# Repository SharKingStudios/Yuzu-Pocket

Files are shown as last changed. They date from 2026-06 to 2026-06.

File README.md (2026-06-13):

# Yuzu Pocket - A PCB Business card that runs Linux!

### compact and delightfully unnecessary.

---

## Renders
*Visuals because everyone loves eye candy.*

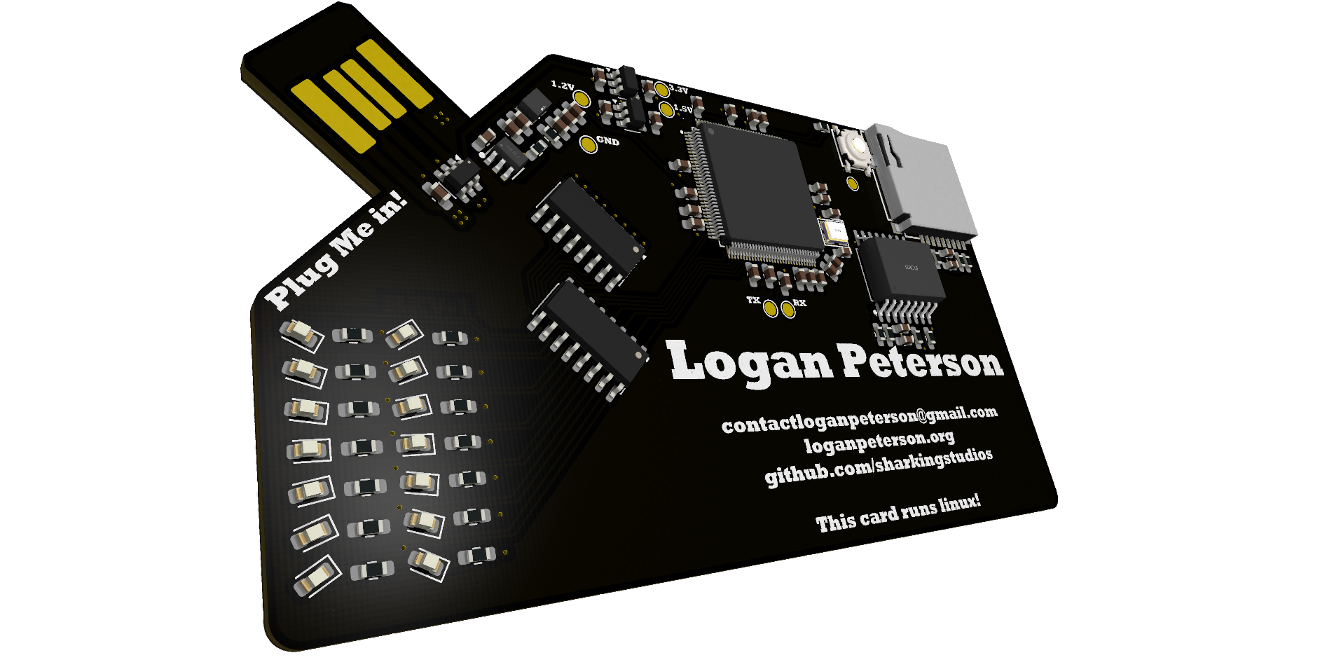
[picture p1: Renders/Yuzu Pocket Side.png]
Side PCB Render

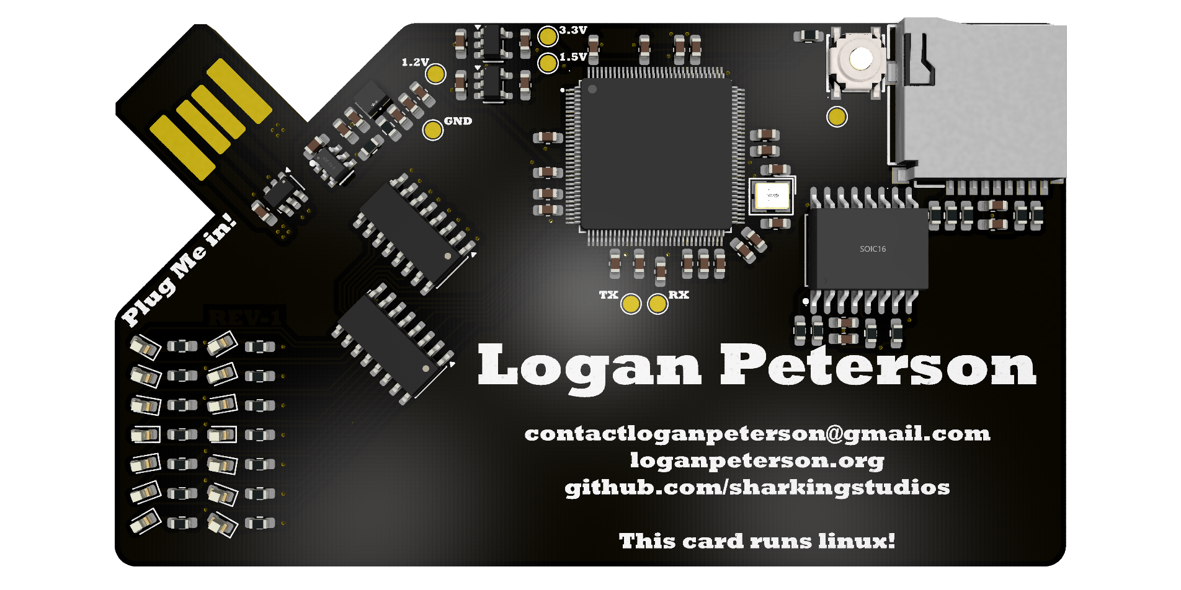
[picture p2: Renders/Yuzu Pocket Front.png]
Top PCB Render

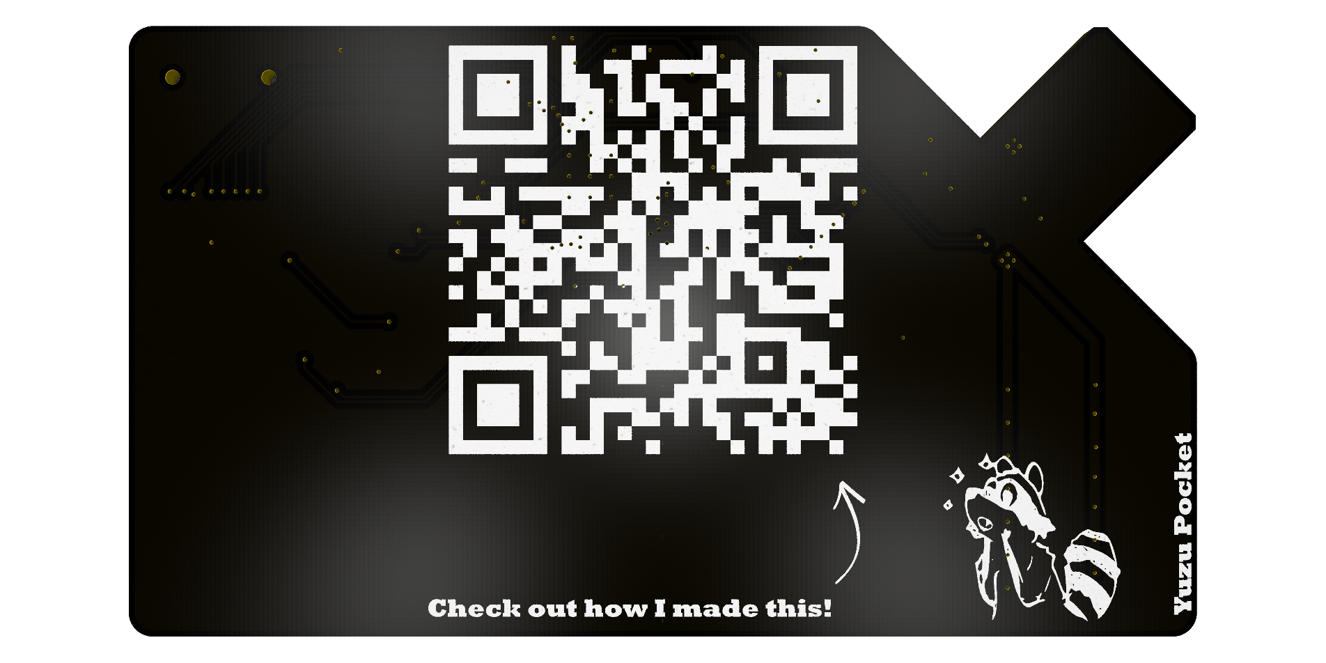
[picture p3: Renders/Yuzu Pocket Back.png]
Back PCB Render

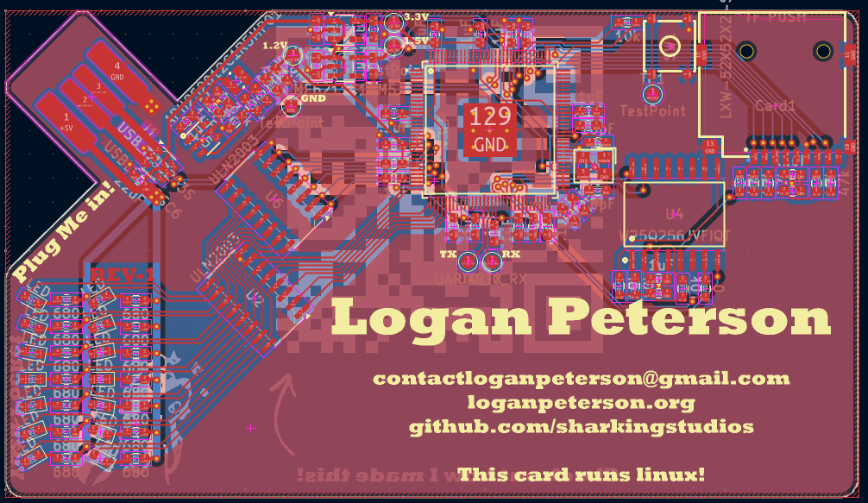
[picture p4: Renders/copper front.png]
Routing Glamour Shot

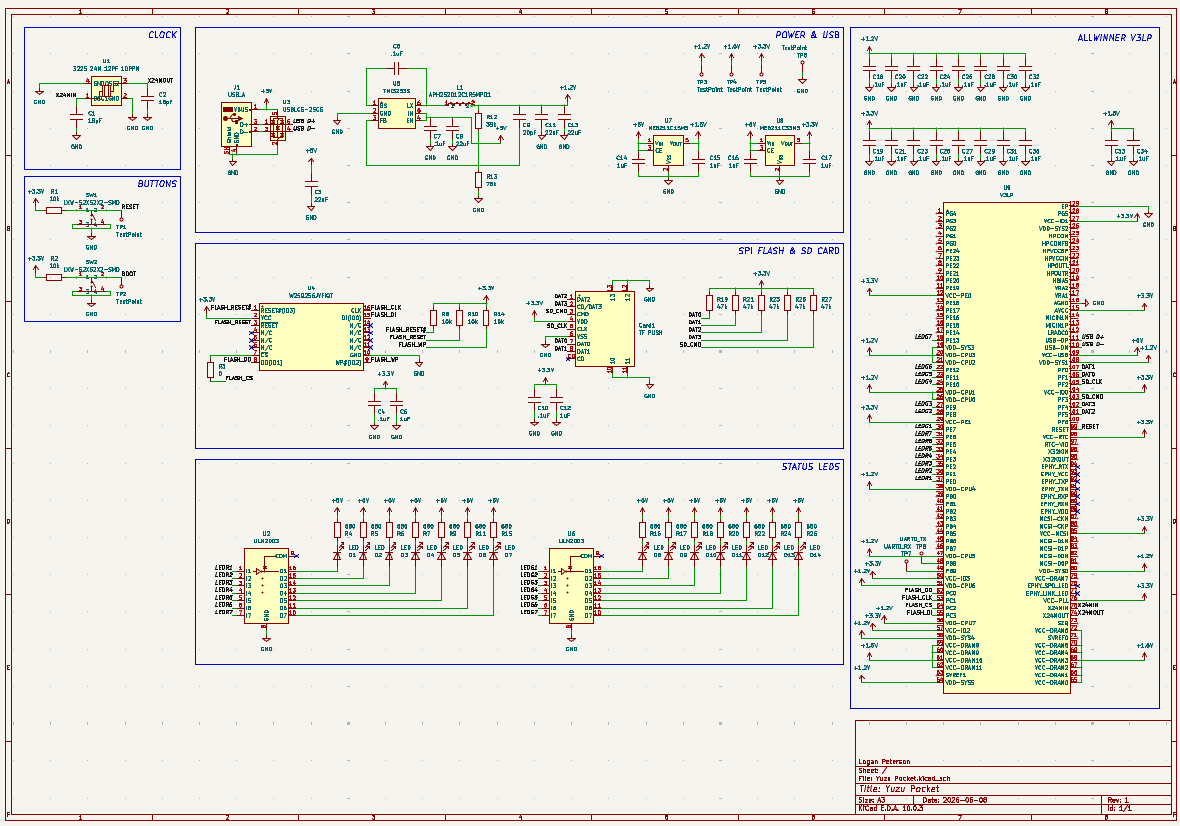
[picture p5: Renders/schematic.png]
Schematic Picture


---

## BOM
All the processors and storage sit **[here](/BOM.csv)**.

**Main characters:**
 - **Processor:** Allwinner V3LP
 - **Onboard Storage:** Winbond W25Q256JVFIQT 256Mbit SPI flash
 - **More Storage:** Micro SD Card Slot
 - **Blinken Lights:** Red and Green
- **Misc:** Boot circuitry, reset logic, pull-ups, decoupling, and other necessary magic

(See `BOM.md` for full part values, footprints, and sourcing.)

---

## What is this?

The **Yuzu Pocket** is a **Business Card that runs Linux** built around an Allwinner V3LP processor, designed to give important individuals my portfolio with some pizzazz!

It does this using its onboard USB port, integrated right into the PCB copper, to talk to the host computer. To keep things interesting, the board exposes itself as a USB gadget, giving the host multiple points of access into the board. 

## How It Works

On startup, the board will connect to the host computer and expose itself as a network device, as well as a mass storage device.

The mass storage that opens acts as the quick menu, and links the user to the more interesting parts of the project, including the hosted webpage at loganpeterson.local that exposes a shell, giving the user direct access into the device (where they can play the integrated terminal games / demos)

At a high level:

1. **The card is plugged into a USB port**
3. The V3LP boots **U-Boot and Linux**
4. Linux creates a composite USB gadget containing:
   - A small read-only help drive
   - A USB network interface
   - A serial interface
5. The host receives an address on the private USB network
6. The card advertises itself as **`loganpeterson.local`**
7. Opening the included shortcut launches a browser-based terminal
8. The visitor is now using a Linux computer thats the size of a business card

No extra special applications are required other than just having a host computer.

---

## Features

### A Real Linux Computer

Yuzu Pocket is not a microcontroller pretending to be a computer. The Allwinner V3LP contains a **32-bit ARM Cortex-A7 processor** and **64 MB of integrated DDR2 RAM**, giving the board enough room for:

- U-Boot
- A Linux kernel
- BusyBox userspace
- USB gadget services
- A web terminal
- Small native programs, games, and network demos

The firmware is intentionally based on **Buildroot** rather than a full desktop distribution.

---

### Plug-In USB Experience

The copper fingers on the edge of the PCB form a USB-A connector. Plugging the card into a computer is intended to provide both power and communication.

The Linux USB gadget configuration can expose several functions over that single connection:

- **Mass storage**
  - Shows `HOW_TO_USE.txt`
  - Includes browser shortcut files
  - Acts as the card's quick-start menu
- **USB Ethernet**
  - Creates a private network between the host and Yuzu Pocket
  - Uses `10.0.0.1` as a fallback address
- **USB serial**
  - Provides another route into the Linux console
- **Web terminal**
  - Served by [`ttyd`](https://github.com/tsl0922/ttyd)
  - Intended URL: **`http://loganpeterson.local:7681/`**

---

### Onboard Storage

Yuzu Pocket has two storage paths:

| Storage | Capacity | Purpose |
|---|---:|---|
| Winbond W25Q256 SPI NOR | 256 Mbit / 32 MB | Compact onboard firmware and persistent assets |
| microSD | Card dependent | Development, recovery, larger Linux images, and *experiments* |

The initial development image targets microSD because it is easier to rebuild and recover. The final compact image is intended to fit within the **32 MB onboard SPI NOR**, using a small kernel and compressed root filesystem.

That storage budget is tight enough to be interesting, but large enough for a fun Linux userspace.

---

### Fourteen Blinken Lights

The card includes:

- **7 red LEDs**
- **7 green LEDs**
- **14 total individually controlled channels**

The LEDs are driven through two ULN2003 Darlington transistor arrays. Linux sees them as GPIO-controlled indicators, allowing them to be used for:

- Boot progress
- Storage activity
- USB connection status
- Network activity
- Error codes
- Loading animations
- *Gratuitous blinking*

Because silent business cards are suspicious.

---

## Firmware

Firmware lives in **[`Firmware/`](/Firmware/)** and is organized as a Buildroot external tree.

The closest upstream starting point is the **Allwinner V3s / Lichee Pi Zero** support found in U-Boot and Linux. V3LP is treated as V3s-like for the initial port, with DRAM initialization being the part most likely to require V3LP-specific work.

See the **[firmware README](/Firmware/README.md)** for build commands, image layout, and current implementation details.

## What Can It Run?

The target is small native Linux software.

This includes:

- Terminal games
- LED animations
- Tiny HTTP services
- Network experiments
- My Portfolio
- A minimal Minecraft-protocol-compatible server
- Whatever fits inside the remaining storage budget

> There is an integration point reserved for [`p2r3/bareiron`](https://github.com/p2r3/bareiron), a compact C Minecraft server experiment. It is not enabled by default yet because upstream requires generated Minecraft registry data before compilation (and I havent gotten to that).

---

## Why?

The **Yuzu Pocket** exists because I wanted a portfolio piece that people would actually remember, rather than another ordinary business card or QR code printed on cardstock (though it has one too!).

It combines my interest in PCB design, embedded systems, and questionable software experiments into something small enough to carry everywhere and hand out to people.

---

## Contributing

Ideas, fixes, experiments, and constructive criticism are welcome.

- Open an issue
- Submit a pull request
- Suggest a tiny program that belongs on the card
- Improve the V3LP boot support
- Help reduce the image size
- Find a fun use for fourteen LEDs
- Make the DOOM situation worse

Please keep PCB and firmware changes clearly separated. Hardware files live in `PCB/`; firmware and build integration belong in `Firmware/`.

---

## Disclaimer

This is an open hardware and firmware project under active development.

It includes:

- Custom power regulation
- Fine-pitch PCB assembly
- USB hardware
- Boot firmware
- Flashing tools capable of overwriting storage
- Enough exposed engineering decisions to create exciting new failure modes

If you overwrite the wrong drive, short a power rail, install a component backward, or release the magic smoke, the business card will be significantly less useful at networking events.

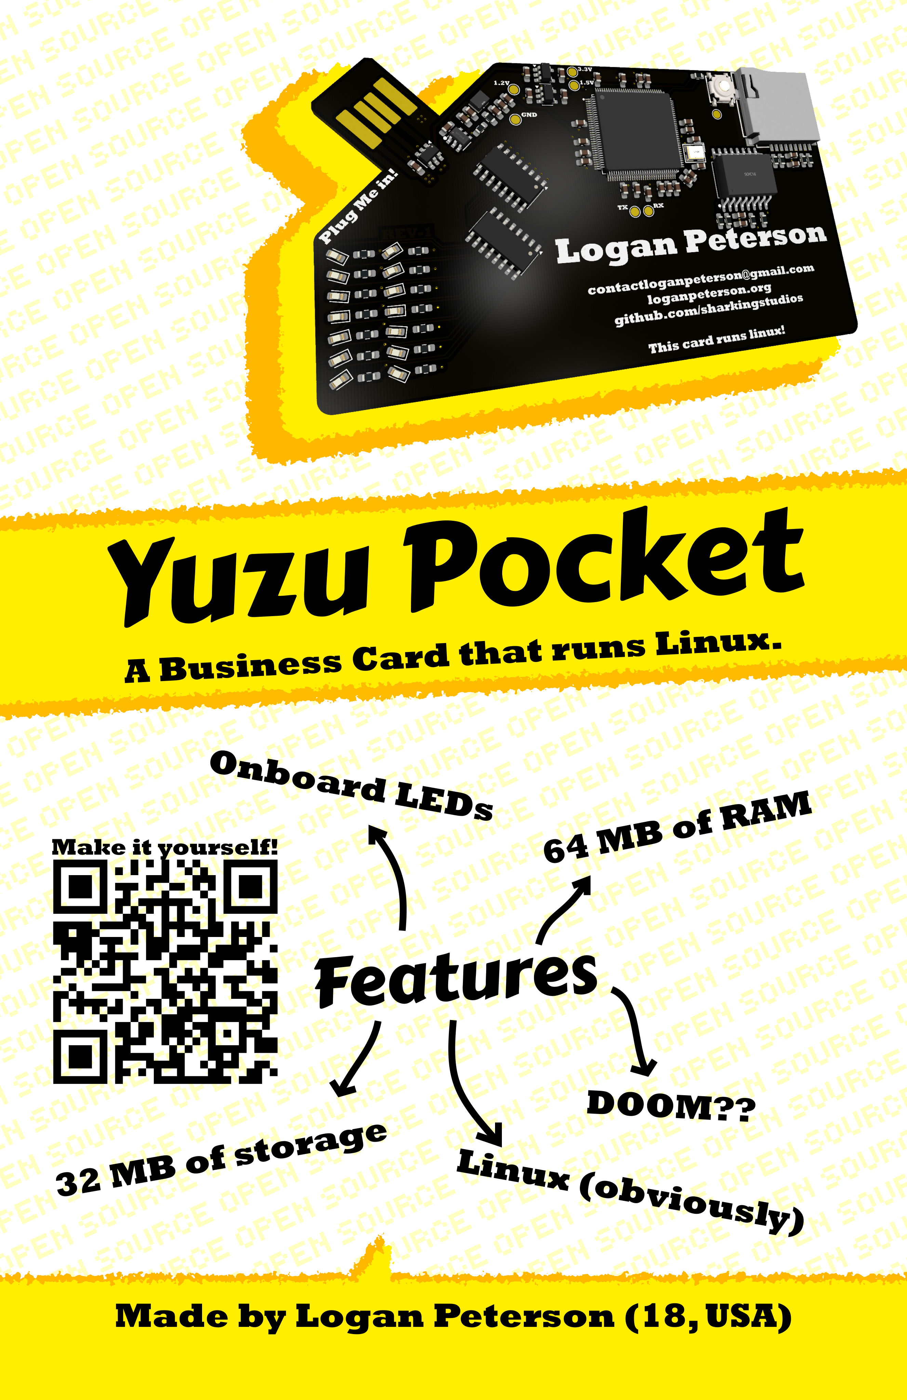
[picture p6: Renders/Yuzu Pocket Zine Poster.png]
Zine Page!


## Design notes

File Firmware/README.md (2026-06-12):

# Yuzu Pocket Firmware

Minimal Linux firmware for the Yuzu Pocket Allwinner V3LP board.

This directory is a Buildroot br2-external tree. It keeps Yuzu Pocket board support in this repo while using a clean upstream Buildroot checkout in `Firmware/buildroot/`.

## Target Image

- U-Boot SPL + U-Boot for the V3s-like sunxi boot path.
- UART0 console on PB8/PB9 at 115200 8N1.
- microSD boot on SDC0/PF0-PF5.
- 64 MB RAM.
- BusyBox rootfs.
- SPI NOR support for W25Q256 JEDEC/MTD detection.
- 14 GPIO LEDs, PE0-PE13, active high through ULN2003 inputs.
- USB gadget setup for ACM serial, ECM network, and a read-only help volume.
- Browser terminal through ttyd at `http://loganpeterson.local:7681/`.
- DHCP/DNS fallback at `http://10.0.0.1:7681/`.

## Quick Start

Run from a Linux or WSL shell with normal Buildroot dependencies installed:

```sh
cd Firmware
sh scripts/fetch-buildroot.sh
sh scripts/build.sh
```

The expected final image is:

```text
Firmware/output/yuzu_pocket/images/sdcard.img
```

## User-Facing Plug-In Flow

When the board boots over USB, it should expose:

- a small read-only help drive with `HOW_TO_USE.txt` and terminal shortcut files,
- a USB network at `10.0.0.1`,
- mDNS name `loganpeterson.local`,
- a ttyd web shell on port `7681`.

The files shown to a user are kept in:

```text
board/yuzu-pocket/rootfs_overlay/opt/yuzu-pocket/help/
```

## Source Baseline

- Buildroot: `2026.05`
- Linux: `6.12.93` longterm
- U-Boot: Buildroot-managed custom version `2026.04`
- Closest upstream board model: Allwinner V3s / Lichee Pi Zero

The V3LP-specific assumption is concentrated in the board DTS and U-Boot config fragment. If SPL DRAM init needs vendor V3LP parameters, those belong in `board/yuzu-pocket/uboot/`.

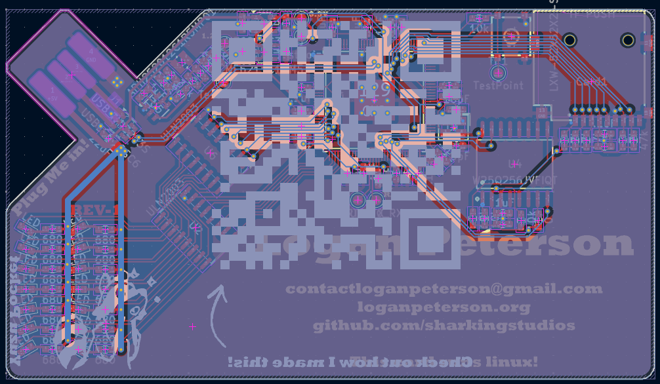
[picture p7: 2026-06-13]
Renders/copper back.png

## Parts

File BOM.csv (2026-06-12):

Value | Qty | Price Ea. | Price total (MOQ) | LCSC link
18pF capacitor 0603 | 2 | 0.0047 | 0.47 | https://www.lcsc.com/product-detail/C107040.html
22uF capacitor 0603 | 4 | 0.23 | 0.45 | https://www.lcsc.com/product-detail/C59461.html
0.1uF capacitor 0603 | 22 | 0.0101 | 1.01 | https://www.lcsc.com/product-detail/C15725.html
1uF capacitor 0603 | 6 | 0.0089 | 0.45 | https://www.lcsc.com/product-detail/C95843.html
20pF capacitor 0603 | 1 | 0.0047 | 0.047 | https://www.lcsc.com/product-detail/C105621.html
SHOU HAN TF PUSH microSD card socket | 1 | 0.063 | 0.63 | https://www.lcsc.com/product-detail/C393941.html
LED 0603 RED | 7 | 0.0035 | 0.35 | https://www.lcsc.com/product-detail/C965799.html
LED 0603 GREEN | 7 | 0.0050 | 0.5 | https://www.lcsc.com/product-detail/C965804.html
APH252012C1R5MP01 (1.5uH SMD inductor) | 1 | 0.034 | 0.68 | https://www.lcsc.com/product-detail/C42455360.html
10k ohm resistor 0603 | 5 | 0.0011 | 0.11 | https://www.lcsc.com/product-detail/C50397040.html
680 ohm resistor 0603 | 14 | 0.001 | 0.10 | https://www.lcsc.com/product-detail/C54921071.html
39k ohm resistor 0603 | 1 | 0.001 | 0.10 | https://www.lcsc.com/product-detail/C54921034.html
78k ohm resistor 0603 | 1 | 0.001 | 0.10 | https://www.lcsc.com/product-detail/C3016126.html
47k ohm resistor 0603 | 5 | 0.0014 | 0.14 | https://www.lcsc.com/product-detail/C2907173.html
LXW-52X52X2-SMD tactile switch | 2 | 0.023 | 0.45 | https://www.lcsc.com/product-detail/C53447014.html
SOSET 3225 24MHz 12pF 10ppm crystal | 1 | 0.069 | 0.69 | https://www.lcsc.com/product-detail/C5181479.html
ULN2003A Darlington transistor array SOIC-16 | 2 | 0.141 | 0.70 | https://www.lcsc.com/product-detail/C7512.html
USBLC6-2SC6 USB ESD protection SOT-23-6 | 1 |  |  | https://www.lcsc.com/product-detail/C7519.html
TMI TMI3253S DC-DC converter SOT-23-6 | 1 | 0.092 | 0.27 | https://www.lcsc.com/product-detail/C478943.html
ME6211C15M5 1.5V LDO regulator SOT-23-5 | 1 | 0.15 | 0.77 | https://www.lcsc.com/product-detail/C53100.html
ME6211C33M5 3.3V LDO regulator SOT-23-5 | 1 | 0.051 | 0.51 | https://www.lcsc.com/product-detail/C82942.html
(For adacent project) OPSCO Optoelectronics SK6812MINI-E | 70 | 0.07 | 4.87 | https://www.lcsc.com/product-detail/C5149201.html
(For adjacent project) ST(Semtech) 1N4148W | 70 | 0.0113 | 2.26 | https://www.lcsc.com/product-detail/C81598.html
Allwinner V3LP processor LQFP-128 | 1 | 2.33 | 4.66 | https://www.superbuy.com/en/page/buy/?url=https%3A%2F%2Fdetail.1688.com%2Foffer%2F1050707306347.html
Winbond W25Q256JVFIQT 256Mbit SPI flash | 1 | 0.4 | 4.00 | https://www.superbuy.com/en/page/buy/?url=https%3A%2F%2Fdetail.1688.com%2Foffer%2F684579822646.html
Estimated Factory Shipping |  |  | 15.00
LCSC Merchandise Subtotal |  |  |  | 17.38
LCSC Shipping Estimate |  |  |  | 12.84
LCSC Taxes Buffer |  |  |  | 3.00
LCSC Total |  |  |  | 33.22
JLCPCB Fabrication | 5 |  |  | 3.30
JLCPCB Stencil | 1 |  |  | 4.00
JLCPCB Shipping Estimate |  |  |  | 13.55
JLCPCB Taxes Buffer |  |  |  | 3.00
JLCPCB Total |  |  |  | 20.55
Grand Total |  |  |  | 53.77

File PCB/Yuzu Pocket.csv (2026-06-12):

Reference | Qty | Value | DNP | Exclude from BOM | Exclude from Board | Footprint | Datasheet
C1,C2 | 2 | 18pF |  |  |  | Capacitor_SMD:C_0603_1608Metric_Pad1.08x0.95mm_HandSolder
C3,C8,C11,C13 | 4 | 22uF |  |  |  | Capacitor_SMD:C_0603_1608Metric_Pad1.08x0.95mm_HandSolder
C4,C5,C7,C10,C18,C19,C20,C21,C22,C23,C24,C25,C26,C27,C28,C29,C30,C31,C32,C33,C34,C35 | 22 | .1uF |  |  |  | Capacitor_SMD:C_0603_1608Metric_Pad1.08x0.95mm_HandSolder
C6,C12,C14,C15,C16,C17 | 6 | 1uF |  |  |  | Capacitor_SMD:C_0603_1608Metric_Pad1.08x0.95mm_HandSolder
C9 | 1 | 20pF |  |  |  | Capacitor_SMD:C_0603_1608Metric_Pad1.08x0.95mm_HandSolder
Card1 | 1 | TF PUSH |  |  |  | easyeda2kicad:TF-SMD_TF-PUSH | https://lcsc.com/product-detail/Connector-Card-Sockets_SHOU-HAN-SHOU-HAN-TFDeck-TF-Deck_C393941.html
D1,D2,D3,D4,D5,D6,D7,D8,D9,D10,D11,D12,D13,D14 | 14 | LED |  |  |  | LED_SMD:LED_0603_1608Metric
L1 | 1 | APH252012C1R5MP01 |  |  |  | easyeda2kicad:IND-SMD_APH252012C3R3MP01 | https://www.lcsc.com/datasheet/C42455360.pdf
R1,R2,R8,R10,R14 | 5 | 10k |  |  |  | Resistor_SMD:R_0603_1608Metric_Pad0.98x0.95mm_HandSolder
R3 | 1 | 0 |  |  |  | Resistor_SMD:R_0603_1608Metric_Pad0.98x0.95mm_HandSolder
R4,R5,R6,R7,R9,R11,R15,R16,R17,R18,R20,R22,R24,R26 | 14 | 680 |  |  |  | Resistor_SMD:R_0603_1608Metric_Pad0.98x0.95mm_HandSolder
R12 | 1 | 39k |  |  |  | Resistor_SMD:R_0603_1608Metric_Pad0.98x0.95mm_HandSolder
R13 | 1 | 78k |  |  |  | Resistor_SMD:R_0603_1608Metric_Pad0.98x0.95mm_HandSolder
R19,R21,R23,R25,R27 | 5 | 47k |  |  |  | Resistor_SMD:R_0603_1608Metric_Pad0.98x0.95mm_HandSolder
SW1,SW2 | 2 | LXW-52X52X2-SMD |  |  |  | easyeda2kicad:SW-SMD_4P-L5.2-W5.2-P5.80-LS6.4 | https://www.lcsc.com/datasheet/C53447014.pdf
TP1,TP2,TP3,TP4,TP5,TP6 | 6 | TestPoint |  |  |  | TestPoint:TestPoint_Pad_D1.5mm
TP7 | 1 | UART0_RX |  |  |  | TestPoint:TestPoint_Pad_D1.5mm
TP8 | 1 | UART0_TX |  |  |  | TestPoint:TestPoint_Pad_D1.5mm
U1 | 1 | 3225 24M 12PF 10PPM |  |  |  | easyeda2kicad:CRYSTAL-SMD_4P-L3.2-W2.5-BL | https://www.lcsc.com/datasheet/C5181479.pdf
U2,U6 | 2 | ULN2003 |  |  |  | Package_SO:SOIC-16_3.9x9.9mm_P1.27mm | http://www.ti.com/lit/ds/symlink/uln2003a.pdf
U3 | 1 | USBLC6-2SC6 |  |  |  | Package_TO_SOT_SMD:SOT-23-6 | https://www.st.com/resource/en/datasheet/usblc6-2.pdf
U4 | 1 | W25Q256JVFIQT |  |  |  | easyeda2kicad:SOIC-16_L10.3-W7.5-P1.27-LS10.3-BL | https://lcsc.com/product-detail/FLASH_Winbond-Elec-W25Q256JVFIQT_C779876.html
U5 | 1 | TMI3253S |  |  |  | easyeda2kicad:SOT-23-6_L2.9-W1.6-P0.95-LS2.8-BL | https://lcsc.com/product-detail/DC-DC-Converters_TMI-TMI3253S_C478943.html
U7 | 1 | ME6211C15M5 |  |  |  | Package_TO_SOT_SMD:SOT-23-5 | https://www.lcsc.com/datasheet/lcsc_datasheet_2304140030_MICRONE-Nanjing-Micro-One-Elec-ME6211C33R5G_C235316.pdf
U8 | 1 | ME6211C33M5 |  |  |  | Package_TO_SOT_SMD:SOT-23-5 | https://www.lcsc.com/datasheet/lcsc_datasheet_2304140030_MICRONE-Nanjing-Micro-One-Elec-ME6211C33R5G_C235316.pdf
U9 | 1 | V3LP |  |  |  | easyeda2kicad:LQFP-128_L14.0-W14.0-P0.40-LS16.0-BL-EP5.6 | https://www.lcsc.com/datasheet/C5350798.pdf

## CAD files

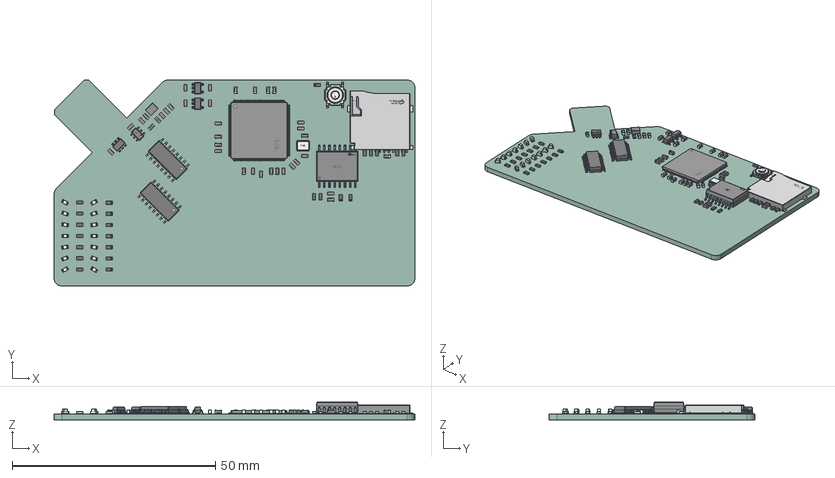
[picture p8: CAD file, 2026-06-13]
PCB/.step
88.9 x 50.8 x 4.40 mm
R_0603_1608Metric x 26
OSC-SMD_L3.2-W1.5-H0.8
SOIC-16_L10.3-W7.5-H2.7-LS10.3-P1.27
C_0603_1608Metric x 35
LED_0603_1608Metric x 14
SOT-23-6
TF-SMD_TF-PUSH
IND-SMD_APH252012C3R3MP01
SOIC-16_3.9x9.9mm_P1.27mm x 2
SOT-23-5 x 2
LQFP-128_L14.0-W14.0-P0.40-LS16.0-BL-EP5.6
SW-SMD_4P-L5.2-W5.2-P5.80-LS6.4
SOT-23-6_L2.9-W1.6-H1.5-LS2.8-P0.95
Yuzu Pocket_PCB

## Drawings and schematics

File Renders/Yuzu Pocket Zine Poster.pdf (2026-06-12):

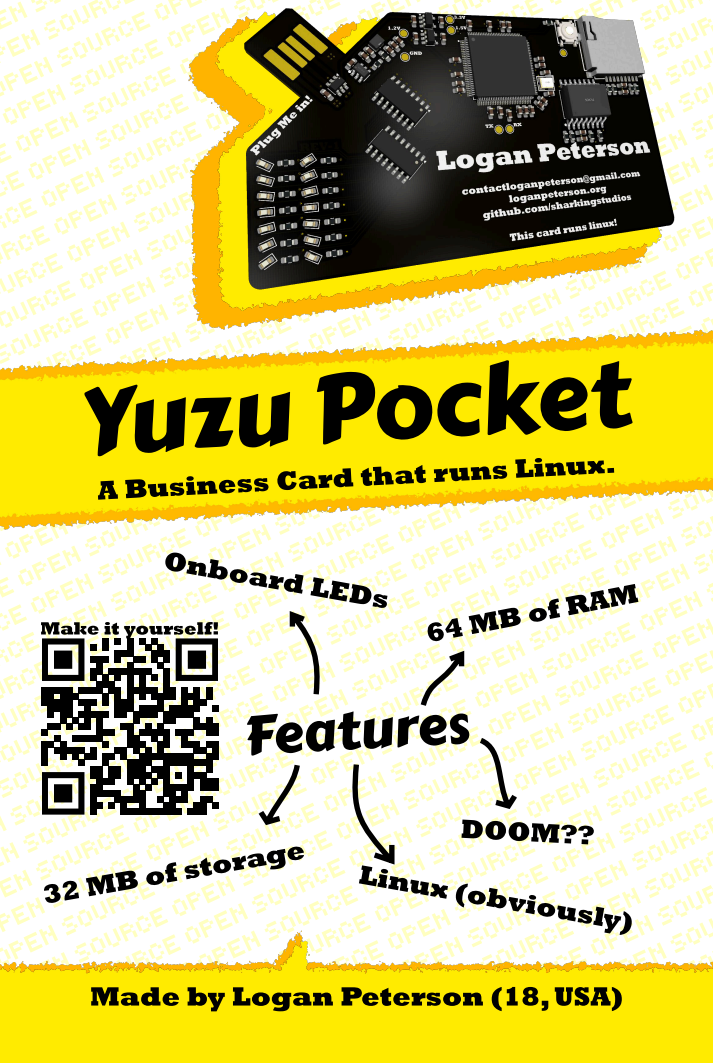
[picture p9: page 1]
Yuzu Pocket; Onboard LEDs; Features; Linux (obviously); DOOM??

OPEN SOURCE OPEN SOURCE OPEN SOURCE OPEN SOURCE OPEN SOURCE OPEN SOURCE OPEN SOURCE

A Business Card that runs Linux.

64 MB of RAM

Make it yourself!

32 MB of storage

Made by Logan Peterson (18, USA)

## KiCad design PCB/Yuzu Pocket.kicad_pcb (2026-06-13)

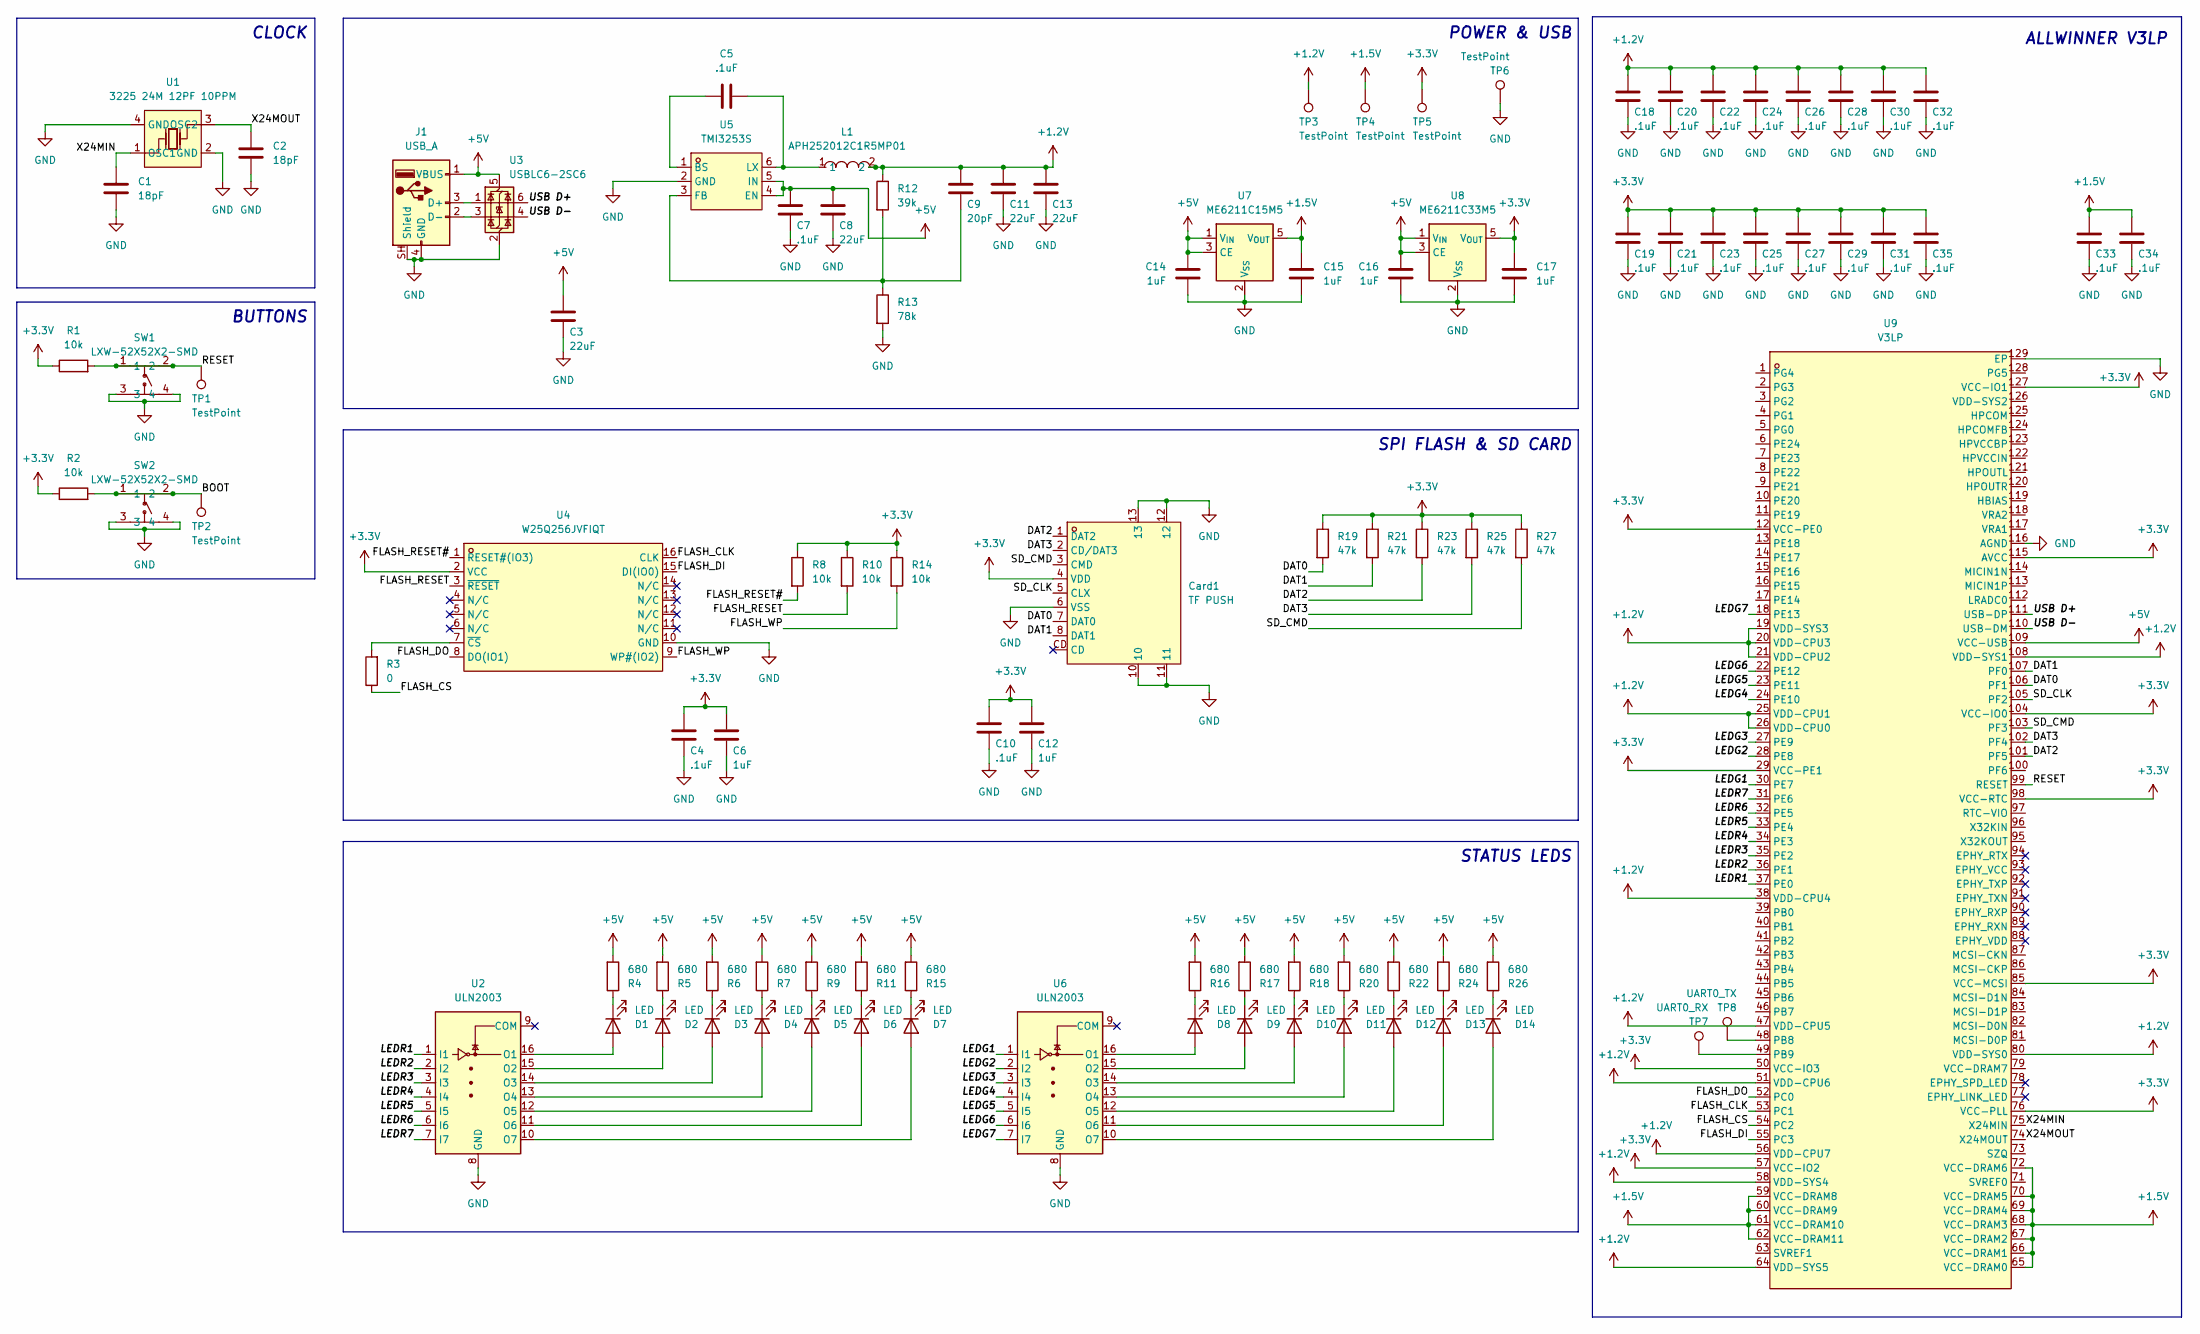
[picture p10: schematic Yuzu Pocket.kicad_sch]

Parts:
C1, C2: 18pF; C_0603_1608Metric_Pad1.08x0.95mm_HandSolder
C3, C8, C11, C13: 22uF; C_0603_1608Metric_Pad1.08x0.95mm_HandSolder
C4, C5, C7, C10, C18, C19, C20, C21, C22, C23, C24, C25, C26, C27, C28, C29, C30, C31, C32, C33, C34, C35: .1uF; C_0603_1608Metric_Pad1.08x0.95mm_HandSolder
C6, C12, C14, C15, C16, C17: 1uF; C_0603_1608Metric_Pad1.08x0.95mm_HandSolder
C9: 20pF; C_0603_1608Metric_Pad1.08x0.95mm_HandSolder
Card1: TF PUSH; TF-SMD_TF-PUSH; MPN TF PUSH; LCSC Part C393941
D1, D2, D3, D4, D5, D6, D7, D8, D9, D10, D11, D12, D13, D14: LED; LED_0603_1608Metric
J1: USB_A; USB_A_PCB_Edge_receptacle
L1: APH252012C1R5MP01; IND-SMD_APH252012C3R3MP01; MPN APH252012C1R5MP01; LCSC Part C42455360
R1, R2, R8, R10, R14: 10k; R_0603_1608Metric_Pad0.98x0.95mm_HandSolder
R3: 0; R_0603_1608Metric_Pad0.98x0.95mm_HandSolder
R4, R5, R6, R7, R9, R11, R15, R16, R17, R18, R20, R22, R24, R26: 680; R_0603_1608Metric_Pad0.98x0.95mm_HandSolder
R12: 39k; R_0603_1608Metric_Pad0.98x0.95mm_HandSolder
R13: 78k; R_0603_1608Metric_Pad0.98x0.95mm_HandSolder
R19, R21, R23, R25, R27: 47k; R_0603_1608Metric_Pad0.98x0.95mm_HandSolder
SW1, SW2: LXW-52X52X2-SMD; SW-SMD_4P-L5.2-W5.2-P5.80-LS6.4; MPN LXW-52X52X2-SMD; LCSC Part C53447014
TP1, TP2, TP3, TP4, TP5, TP6: TestPoint; TestPoint_Pad_D1.5mm
TP7: UART0_RX; TestPoint_Pad_D1.5mm
TP8: UART0_TX; TestPoint_Pad_D1.5mm
U1: 3225 24M 12PF 10PPM; CRYSTAL-SMD_4P-L3.2-W2.5-BL; MPN 3225 24M 12PF 10PPM; LCSC Part C5181479
U2, U6: ULN2003; SOIC-16_3.9x9.9mm_P1.27mm
U3: USBLC6-2SC6; SOT-23-6
U4: W25Q256JVFIQT; SOIC-16_L10.3-W7.5-P1.27-LS10.3-BL; MPN W25Q256JVFIQ; LCSC Part C779876
U5: TMI3253S; SOT-23-6_L2.9-W1.6-P0.95-LS2.8-BL; MPN TMI3253S; LCSC Part C478943
U7: ME6211C15M5; SOT-23-5
U8: ME6211C33M5; SOT-23-5
U9: V3LP; LQFP-128_L14.0-W14.0-P0.40-LS16.0-BL-EP5.6; MPN V3LP; LCSC Part C5350798

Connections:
+1.2V: C9.2, C11.2, C13.2, C18.2, C20.2, C22.2, C24.2, C26.2, C28.2, C30.2, C32.2, L1.2, R12.1, TP3.1 (1_1), U9.19 (VDD-SYS3), U9.20 (VDD-CPU3), U9.21 (VDD-CPU2), U9.25 (VDD-CPU1), U9.26 (VDD-CPU0), U9.38 (VDD-CPU4), U9.47 (VDD-CPU5), U9.51 (VDD-CPU6), U9.56 (VDD-CPU7), U9.58 (VDD-SYS4), U9.64 (VDD-SYS5), U9.80 (VDD-SYS0), U9.108 (VDD-SYS1)
+1.5V: C15.1, C33.2, C34.2, TP4.1 (1_1), U7.5 (V_{OUT}), U9.59 (VCC-DRAM8), U9.60 (VCC-DRAM9), U9.61 (VCC-DRAM10), U9.62 (VCC-DRAM11), U9.65 (VCC-DRAM0), U9.66 (VCC-DRAM1), U9.67 (VCC-DRAM2), U9.68 (VCC-DRAM3), U9.69 (VCC-DRAM4), U9.70 (VCC-DRAM5), U9.72 (VCC-DRAM6)
+3.3V: C4.2, C6.2, C10.2, C12.2, C17.1, C19.2, C21.2, C23.2, C25.2, C27.2, C29.2, C31.2, C35.2, Card1.4 (VDD), R1.1, R2.1, R8.1, R10.1, R14.1, R19.1, R21.1, R23.1, R25.1, R27.1, TP5.1 (1_1), U4.2 (VCC), U8.5 (V_{OUT}), U9.12 (VCC-PE0), U9.29 (VCC-PE1), U9.50 (VCC-IO3), U9.57 (VCC-IO2), U9.76 (VCC-PLL), U9.85 (VCC-MCSI), U9.98 (VCC-RTC), U9.104 (VCC-IO0), U9.115 (AVCC), U9.127 (VCC-IO1)
+5V: C3.2, C7.2, C8.2, C14.2, C16.2, J1.1 (VBUS), R4.2, R5.2, R6.2, R7.2, R9.2, R11.2, R15.2, R16.2, R17.2, R18.2, R20.2, R22.2, R24.2, R26.2, U3.5 (VBUS), U5.4 (EN), U5.5 (IN), U7.1 (V_{IN}), U7.3 (CE), U8.1 (V_{IN}), U8.3 (CE), U9.109 (VCC-USB)
/DAT0: Card1.7 (DAT0), R19.2, U9.106 (PF1)
/DAT1: Card1.8 (DAT1), R21.2, U9.107 (PF0)
/DAT2: Card1.1 (DAT2), R23.2, U9.101 (PF5)
/DAT3: Card1.2 (CD/DAT3), R25.2, U9.102 (PF4)
/FLASH_CLK: U4.16 (CLK), U9.53 (PC1)
/FLASH_CS: R3.1, U9.54 (PC2)
/FLASH_DI: U4.15 (DI(IO0)), U9.55 (PC3)
/FLASH_DO: U4.8 (DO(IO1)), U9.52 (PC0)
/FLASH_RESET: R10.2, U4.3 (~RESET)
/FLASH_RESET#: R8.2, U4.1 (RESET#(IO3))
/FLASH_WP: R14.2, U4.9 (WP#(IO2))
/LEDG1: U6.1 (I1), U9.30 (PE7)
/LEDG2: U6.2 (I2), U9.28 (PE8)
/LEDG3: U6.3 (I3), U9.27 (PE9)
/LEDG4: U6.4 (I4), U9.24 (PE10)
/LEDG5: U6.5 (I5), U9.23 (PE11)
/LEDG6: U6.6 (I6), U9.22 (PE12)
/LEDG7: U6.7 (I7), U9.18 (PE13)
/LEDR1: U2.1 (I1), U9.37 (PE0)
/LEDR2: U2.2 (I2), U9.36 (PE1)
/LEDR3: U2.3 (I3), U9.35 (PE2)
/LEDR4: U2.4 (I4), U9.34 (PE3)
/LEDR5: U2.5 (I5), U9.33 (PE4)
/LEDR6: U2.6 (I6), U9.32 (PE5)
/LEDR7: U2.7 (I7), U9.31 (PE6)
/RESET: R1.2, SW1.1, SW1.2, TP1.1 (1_1), U9.99 (RESET)
/SD_CLK: Card1.5 (CLX), U9.105 (PF2)
/SD_CMD: Card1.3 (CMD), R27.2, U9.103 (PF3)
/USB D+: U3.6 (I/O1), U9.111 (USB-DP)
/USB D-: U3.4 (I/O2), U9.110 (USB-DM)
/X24MIN: C1.1, U1.1 (OSC1), U9.75 (X24MIN)
/X24MOUT: C2.1, U1.3 (OSC2), U9.74 (X24MOUT)
GND: C1.2, C2.2, C3.1, C4.1, C6.1, C7.1, C8.1, C10.1, C11.1, C12.1, C13.1, C14.1, C15.2, C16.1, C17.2, C18.1, C19.1, C20.1, C21.1, C22.1, C23.1, C24.1, C25.1, C26.1, C27.1, C28.1, C29.1, C30.1, C31.1, C32.1, C33.1, C34.1, C35.1, Card1.6 (VSS), Card1.10, Card1.11, Card1.12, Card1.13, J1.4 (GND), J1.SH (Shield), R13.2, SW1.3, SW1.4, SW2.3, SW2.4, TP6.1 (1_1), U1.2 (GND), U1.4 (GND), U2.8 (GND), U3.2 (GND), U4.10 (GND), U5.2 (GND), U6.8 (GND), U7.2 (V_{SS}), U8.2 (V_{SS}), U9.116 (AGND), U9.129 (EP)
unnamed: D1.2 (A), U2.16 (O1)
unnamed: D1.1 (K), R4.1
unnamed: D2.2 (A), U2.15 (O2)
unnamed: D2.1 (K), R5.1
unnamed: D3.2 (A), U2.14 (O3)
unnamed: D3.1 (K), R6.1
unnamed: D4.2 (A), U2.13 (O4)
unnamed: D4.1 (K), R7.1
unnamed: D5.2 (A), U2.12 (O5)
unnamed: D5.1 (K), R9.1
unnamed: D6.2 (A), U2.11 (O6)
unnamed: D6.1 (K), R11.1
unnamed: D7.2 (A), U2.10 (O7)
unnamed: D7.1 (K), R15.1
unnamed: D8.2 (A), U6.16 (O1)
unnamed: D8.1 (K), R16.1
unnamed: D9.2 (A), U6.15 (O2)
unnamed: D9.1 (K), R17.1
unnamed: D10.2 (A), U6.14 (O3)
unnamed: D10.1 (K), R18.1
unnamed: D11.2 (A), U6.13 (O4)
unnamed: D11.1 (K), R20.1
unnamed: D12.2 (A), U6.12 (O5)
unnamed: D12.1 (K), R22.1
unnamed: D13.2 (A), U6.11 (O6)
unnamed: D13.1 (K), R24.1
unnamed: D14.2 (A), U6.10 (O7)
unnamed: D14.1 (K), R26.1
unnamed: J1.3 (D+), U3.1 (I/O1)
unnamed: J1.2 (D-), U3.3 (I/O2)
unnamed: R2.2, SW2.1, SW2.2, TP2.1
unnamed: R3.2, U4.7 (~CS)
unnamed: C5.1, U5.1 (BS)
unnamed: C9.1, R12.2, R13.1, U5.3 (FB)
unnamed: C5.2, L1.1, U5.6 (LX)
unnamed: TP8.1 (1_1), U9.48 (PB8)
unnamed: TP7.1 (1_1), U9.49 (PB9)

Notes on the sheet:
BUTTONS
CLOCK
ALLWINNER V3LP
POWER & USB
SPI FLASH & SD CARD
STATUS LEDS

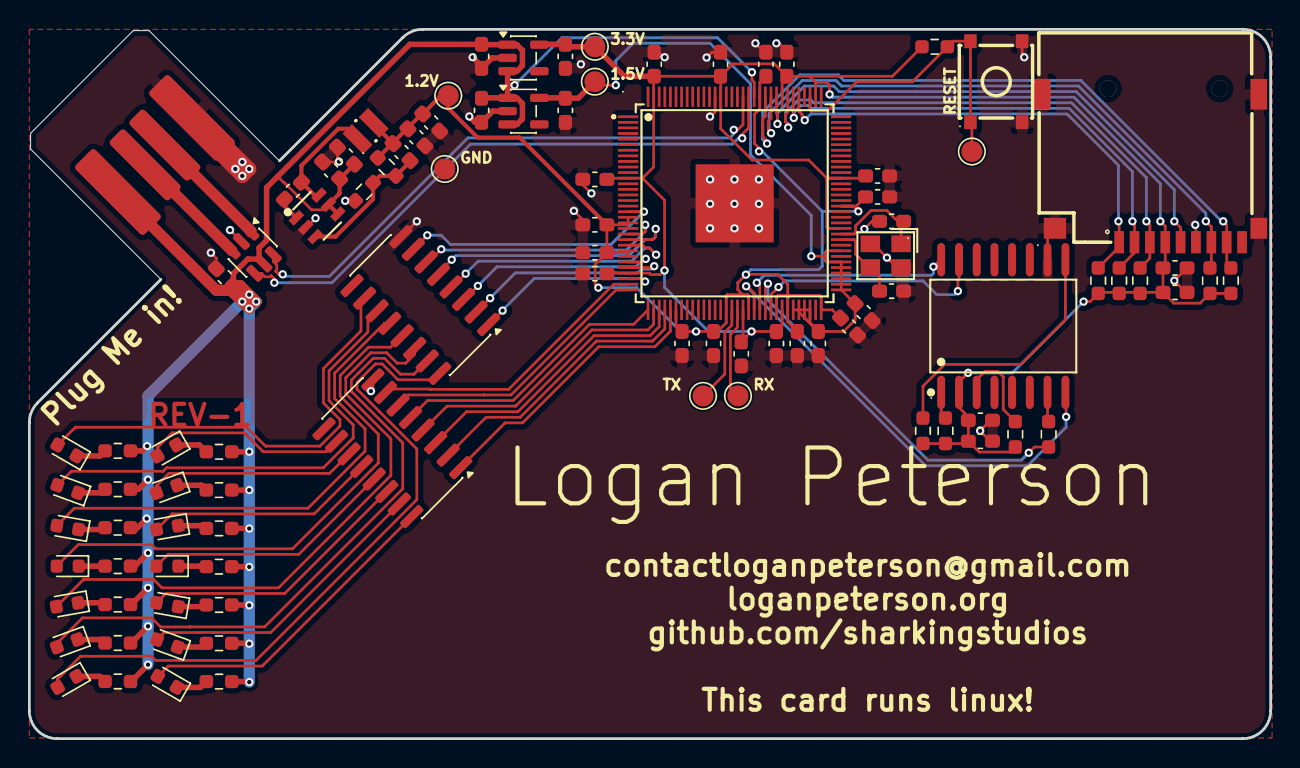
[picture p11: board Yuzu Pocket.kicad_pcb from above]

Board: 2 copper layers, 88.9 x 50.8 mm, 95 parts (0 on the bottom side), 73 nets.

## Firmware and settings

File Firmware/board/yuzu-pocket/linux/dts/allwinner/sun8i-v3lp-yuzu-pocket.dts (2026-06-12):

// SPDX-License-Identifier: (GPL-2.0+ OR MIT)
/*
 * Yuzu Pocket business-card Linux board.
 *
 * V3LP is treated as V3s-compatible for this first firmware target.
 * Confirmed board differences from Lichee Pi Zero are captured here.
 */

/dts-v1/;
#include "sun8i-v3s.dtsi"
#include "sunxi-common-regulators.dtsi"
#include <dt-bindings/gpio/gpio.h>

/ {
	model = "Yuzu Pocket V3LP";
	compatible = "yuzu,yuzu-pocket-v3lp", "allwinner,sun8i-v3s";

	aliases {
		serial0 = &uart0;
		mmc0 = &mmc0;
		spi0 = &spi0;
	};

	chosen {
		stdout-path = "serial0:115200n8";
		bootargs = "console=ttyS0,115200 earlycon root=/dev/mmcblk0p2 rootwait rw panic=5";
	};

	memory@40000000 {
		device_type = "memory";
		reg = <0x40000000 0x04000000>;
	};

	leds {
		compatible = "gpio-leds";

		red1 {
			label = "yuzu:red:1";
			gpios = <&pio 4 0 GPIO_ACTIVE_HIGH>; /* PE0 */
		};

		red2 {
			label = "yuzu:red:2";
			gpios = <&pio 4 1 GPIO_ACTIVE_HIGH>; /* PE1 */
		};

		red3 {
			label = "yuzu:red:3";
			gpios = <&pio 4 2 GPIO_ACTIVE_HIGH>; /* PE2 */
		};

		red4 {
			label = "yuzu:red:4";
			gpios = <&pio 4 3 GPIO_ACTIVE_HIGH>; /* PE3 */
		};

		red5 {
			label = "yuzu:red:5";
			gpios = <&pio 4 4 GPIO_ACTIVE_HIGH>; /* PE4 */
		};

		red6 {
			label = "yuzu:red:6";
			gpios = <&pio 4 5 GPIO_ACTIVE_HIGH>; /* PE5 */
		};

		red7 {
			label = "yuzu:red:7";
			gpios = <&pio 4 6 GPIO_ACTIVE_HIGH>; /* PE6 */
		};

		green1 {
			label = "yuzu:green:1";
			gpios = <&pio 4 7 GPIO_ACTIVE_HIGH>; /* PE7 */
		};

		green2 {
			label = "yuzu:green:2";
			gpios = <&pio 4 8 GPIO_ACTIVE_HIGH>; /* PE8 */
		};

		green3 {
			label = "yuzu:green:3";
			gpios = <&pio 4 9 GPIO_ACTIVE_HIGH>; /* PE9 */
		};

		green4 {
			label = "yuzu:green:4";
			gpios = <&pio 4 10 GPIO_ACTIVE_HIGH>; /* PE10 */
		};

		green5 {
			label = "yuzu:green:5";
			gpios = <&pio 4 11 GPIO_ACTIVE_HIGH>; /* PE11 */
		};

		green6 {
			label = "yuzu:green:6";
			gpios = <&pio 4 12 GPIO_ACTIVE_HIGH>; /* PE12 */
		};

		green7 {
			label = "yuzu:green:7";
			gpios = <&pio 4 13 GPIO_ACTIVE_HIGH>; /* PE13 */
		};
	};
};

&mmc0 {
	broken-cd;
	bus-width = <4>;
	vmmc-supply = <&reg_vcc3v3>;
	status = "okay";
};

&spi0 {
	pinctrl-0 = <&spi0_pins>;
	pinctrl-names = "default";
	status = "okay";

	flash@0 {
		compatible = "jedec,spi-nor";
		reg = <0>;
		spi-max-frequency = <50000000>;
	};
};

&uart0 {
	pinctrl-0 = <&uart0_pb_pins>;
	pinctrl-names = "default";
	status = "okay";
};

&usb_otg {
	dr_mode = "peripheral";
	status = "okay";
};

&usbphy {
	status = "okay";
};

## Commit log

2026-06-09 Selected Processor
    Selected the Allwinner V3LP as the main processor for the board and started some of the schematic for that.
    [Yuzu Pocket.kicad_pcb, Yuzu Pocket.kicad_sch]
2026-06-10 Schematic done!
    [Yuzu Pocket.kicad_pcb, Yuzu Pocket.kicad_sch]
2026-06-10 PCB Layout + Routing Done
    The business card is ready for silkscreen!
    [Yuzu Pocket.kicad_pcb, Yuzu Pocket.kicad_sch]
2026-06-12 firmware + zine page
    [.step, BOM.csv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]
2026-06-12 Added BOM
    [BOM.csv]
2026-06-13 Updated Gerbers to V1.1 and Fleshed out README
    [.step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]
